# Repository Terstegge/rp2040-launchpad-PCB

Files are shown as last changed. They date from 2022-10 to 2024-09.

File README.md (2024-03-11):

# RP2040-Launchpad PCB

This repository contains the KiCad design files for a TI-style Launchpad board
with the RP2040 microcontroller. The board features a build-in picoprobe
debugger, which signals UART RX/TX and SWD activity with 3 LEDs. The unused
GPIO pins of the picoprobe are connected to a header, which could be used
in the future for more functionality like a simple logic analyzer etc.

The target RP2040 controller has 2 connected pushbuttons, one normal LED and
8 WS2812-2020 LEDs as input/output. Some signals are also available on a
horizonal header at the lower end of the PCB, which is used to connect WLAN or
Bluetooth boards like WifiTick. Both RP2040 (target and picoprobe) use a
4 MiB flash chip. The target RP2040 also has a button to enable programming
via the target USB port (mass storage device). Normally this button is
not needed, because all programming and debugging of the target is performed
via the picoprobe using openocd and gdb.

The board also contains a LiPo-charger to enable battery-powered projects.

Why was this board designed? I have been using the MSP432 Launchpad from TI for
quite a while in university classes teaching microcontroller technology.
Unfortunately TI has stopped producing all MSP432-related products. Still we
have purchased lots of TI boosterpack-boards like the Educational Boosterpack MK II.
The be able to used these Boosterpacks also in the future, a new Launchpad had
to be found. The RP2040 is a very interesting microcontroller, and, what is
quite important for educational purposes, it has excellent documentation.
So some days were spent and this board came to life.

The pictures below show version 1.3. The board features 2 user buttons and
a reset button on the lower edge. Additionally there is one
user-programmable simple red LED and a row of 8 WS2812 LEDS.
 
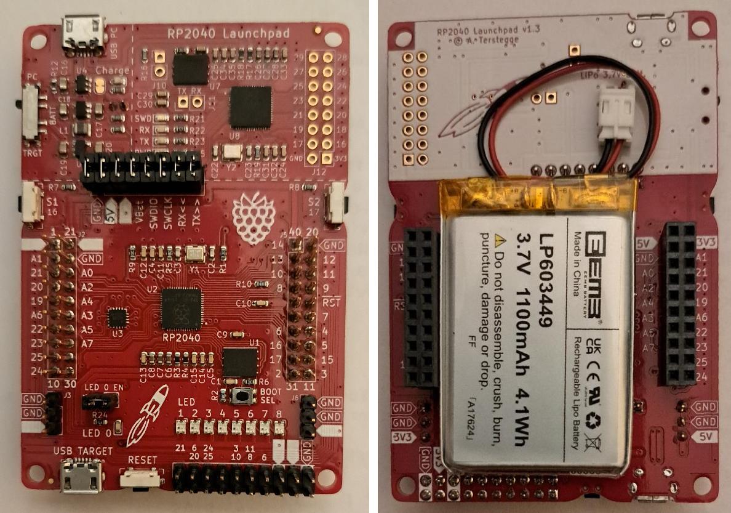
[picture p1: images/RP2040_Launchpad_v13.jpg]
RP2040 Lauchpad picture 1


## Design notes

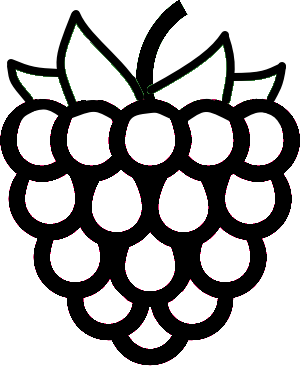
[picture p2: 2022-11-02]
images/raspberry.png

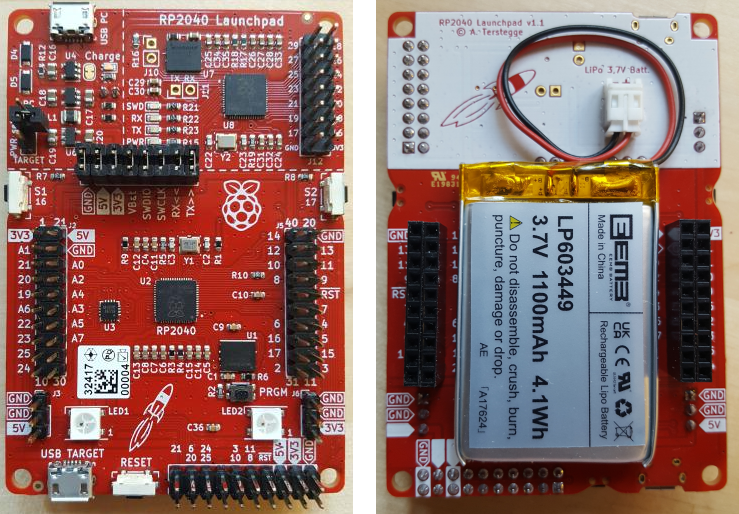
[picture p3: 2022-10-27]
images/rp2040-launchpad.png

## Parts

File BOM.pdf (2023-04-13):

rp2040-launchpad-PCB

Seite 1

ID | Bezeichner | Gehäuse | Stückzahl | Bezeichnung | Anbieter und Referenz
1 | J4 | PinHeader_2x10_P2.54mm_Vertical | 1 | LP Extension Heder
2 | G*** | Lauchpad-Logo | 1 | LOGO
3 | U9,U10,U11,U12,U13,U14,U15,U 16 | WS2812B-2020 | 8 | WS2812B-2020
4 | G***,G*** | raspberry | 2 | LOGO
5 | ,,, | | 4
6 | G***,G*** | Lauchpad-Energia-Logo | 2 | LOGO
7 | USB2 | USB-micro-B-Amph-10118194 | 1 | USB PC
8 | USB1 | USB-micro-B-Amph-10118194 | 1 | USB TARGET
9 | SW1 | DIPT-1188E | 1 | RESET
10 | S2 | DIPT-1188E | 1 | S2
11 | S1 | DIPT-1188E | 1 | S1
12 | SW2 | KMR2-Switch | 1 | BOOT
13 | J2 | PinHeader_2x10_P2.54mm_Vertical | 1 | LP Header left
14 | REF**,REF** | Fiducial_1mm_Mask2mm | 2 | Fiducial_1mm_Mask2mm
15 | U3 | QFN-16-1EP_3x3mm_P0.5mm_EP1.7x1.7mm | 1 | RS2299
16 | R11,R2,R5,R7,R8,R10,R15,R16, R19 | R_0603_1608Metric | 9 | 1k
17 | J8 | JST-S2B-PH-KL | 1 | LiPo 3,7V Batt.
18 | C1,C4,C5,C9,C10,C11,C12,C13, C14,C15,C21,C24,C25,C29,C30, C31,C32,C33,C34,C35 | C_0603_1608Metric | 20 | 100nF
19 | C2,C3,C22,C23 | C_0603_1608Metric | 4 | 22pF
20 | C6,C7,C8,C26,C27,C28 | C_0603_1608Metric | 6 | 1uF
21 | C16,C17,C18,C19,C20 | C_0805_2012Metric | 5 | 22u
22 | D3 | LED_0603_1608Metric | 1 | Charge
23 | D6 | LED_0603_1608Metric | 1 | PWR
24 | D7 | LED_0603_1608Metric | 1 | BLUE
25 | D8 | LED_0603_1608Metric | 1 | GREEN
26 | D9 | LED_0603_1608Metric | 1 | RED
27 | J1 | PinHeader_2x08_P2.54mm_Vertical | 1 | Target Isolation Jumpers
28 | J3,J6 | PinHeader_1x03_P2.54mm_Vertical | 2 | PWR Header
29 | J5 | PinHeader_2x10_P2.54mm_Vertical | 1 | LP Header right
30 | J7 | SolderJumper-2_P1.3mm_Bridged_RoundedPad1.0x1.5mm | 1 | Jumper
31 | J10 | PinHeader_1x02_P2.54mm_Vertical | 1 | DBG_PRGM
32 | J11 | PinHeader_1x02_P2.54mm_Vertical | 1 | UART_DBG
33 | J12 | PinHeader_2x08_P2.54mm_Vertical | 1 | DGB Exp. Header
34 | L1 | L_1008_2520Metric | 1 | 4u7
35 | R1,R6,R9,R20 | R_0603_1608Metric | 4 | 10k
36 | R3,R4,R17,R18 | R_0603_1608Metric | 4 | 27

rp2040-launchpad-PCB

Seite 2

37 | R12 | R_0603_1608Metric | 1 | 2k
38 | R13,R14 | R_0603_1608Metric | 2 | 100k
39 | R21,R22,R23,R24 | R_0603_1608Metric | 4 | 470
40 | U1,U7 | WSON-8-1EP_6x5mm_P1.27mm_EP3.4x4.3mm | 2 | 25Q32
41 | U2,U8 | QFN40P700X700X90-57N | 2 | RP2040
42 | U4 | SOT-23-5 | 1 | MCP73831
43 | U5 | SOT-23-5 | 1 | XC9142B50C
44 | U6 | SOT-23-5 | 1 | XC6220B33
45 | Y1,Y2 | Crystal_SMD_TXC_7M-4Pin_3.2x2.5mm | 2 | 12MHz
46 | D1 | LED_0603_1608Metric | 1 | LED 0
47 | J13 | PinHeader_1x02_P2.54mm_Vertical | 1 | LED 0 EN
48 | SW3 | PCM13SMTR | 1 | Switch_SP3T

kein Bauteil
THT Bauteil, vor vom Kunden betstückt
SMD Bauteil, wird vom Kunden beigestellt
SMD R/C, wird von Fa Kuttig gestellt

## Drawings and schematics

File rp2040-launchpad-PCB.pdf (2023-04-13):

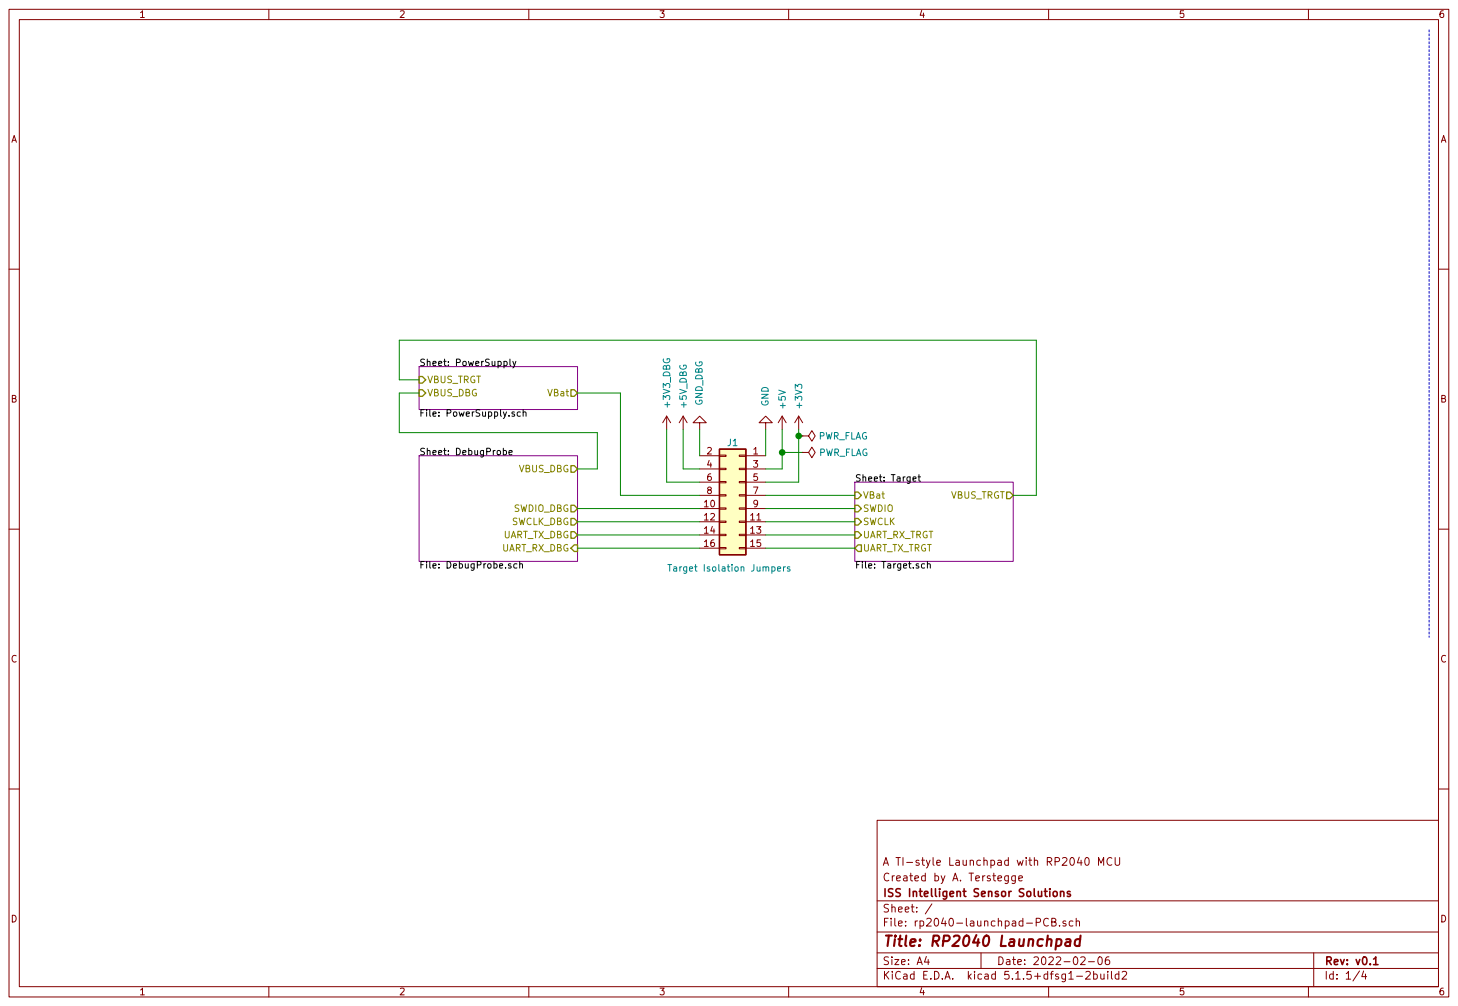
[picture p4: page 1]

SWDIO
File: Target.sch SWCLK

12 | 11
14 | 13
16 | 15

A TI-style Launchpad with RP2040 MCU
Created by A. Terstegge
ISS Intelligent Sensor Solutions
File: rp2040-launchpad-PCB.sch Sheet: /
Id: 1/4 Title: RP2040 Launchpad

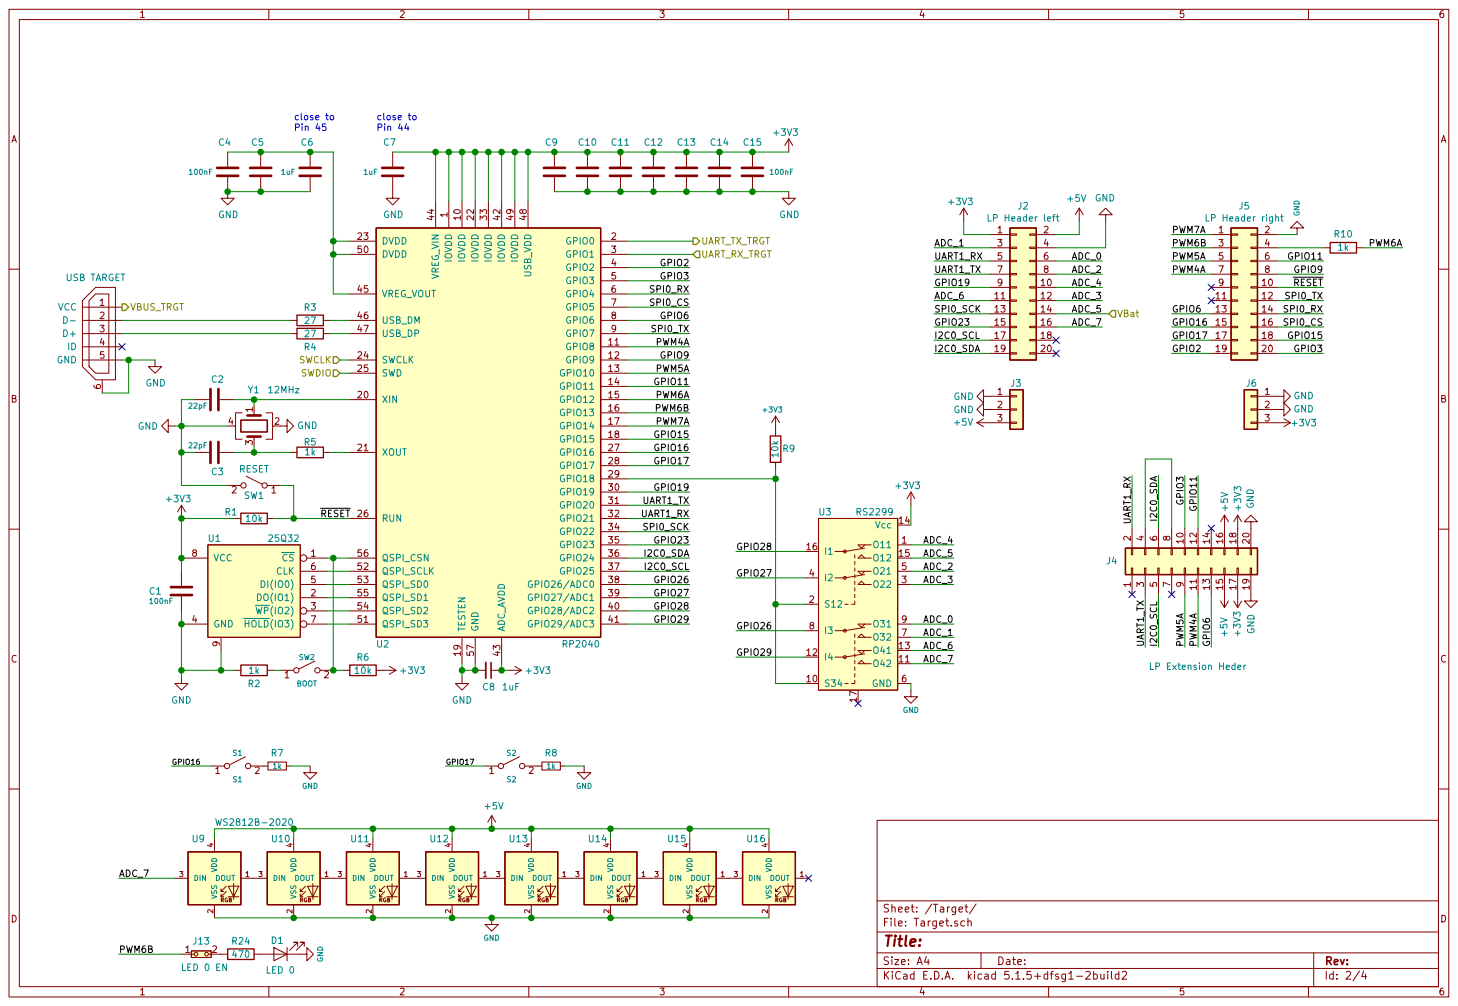
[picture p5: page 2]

1 IOVDD 10 GPIO8 11 GPIO9 12 GPIO10 13 GPIO11 14 GPIO12 15 GPIO13 16 GPIO14 17 GPIO15 18 TESTEN 19 GPIO0 2 XIN 20 XOUT 21 IOVDD 22 DVDD 23 SWCLK 24 SWD 25 RUN 26 GPIO16 27 GPIO17 28 GPIO18 29 GPIO1 3 GPIO19 30 GPIO20 31 GPIO21 32 IOVDD 33 GPIO22 34 GPIO23 35 GPIO24 36 GPIO25 37 GPIO26/ADC0 38 GPIO27/ADC1 39 GPIO2 4 GPIO28/ADC2 40 GPIO29/ADC3 41 IOVDD 42 ADC_AVDD 43 VREG_VIN 44 VREG_VOUT 45 USB_DM 46 USB_DP 47 USB_VDD 48 IOVDD 49 GPIO3 5 DVDD 50 QSPI_SD3 51 QSPI_SCLK 52 QSPI_SD0 53 QSPI_SD2 54 QSPI_SD1 55 QSPI_CSN 56 GND 57 GPIO4 6 GPIO5 7 GPIO6 8 GPIO7 9 U2 RP2040

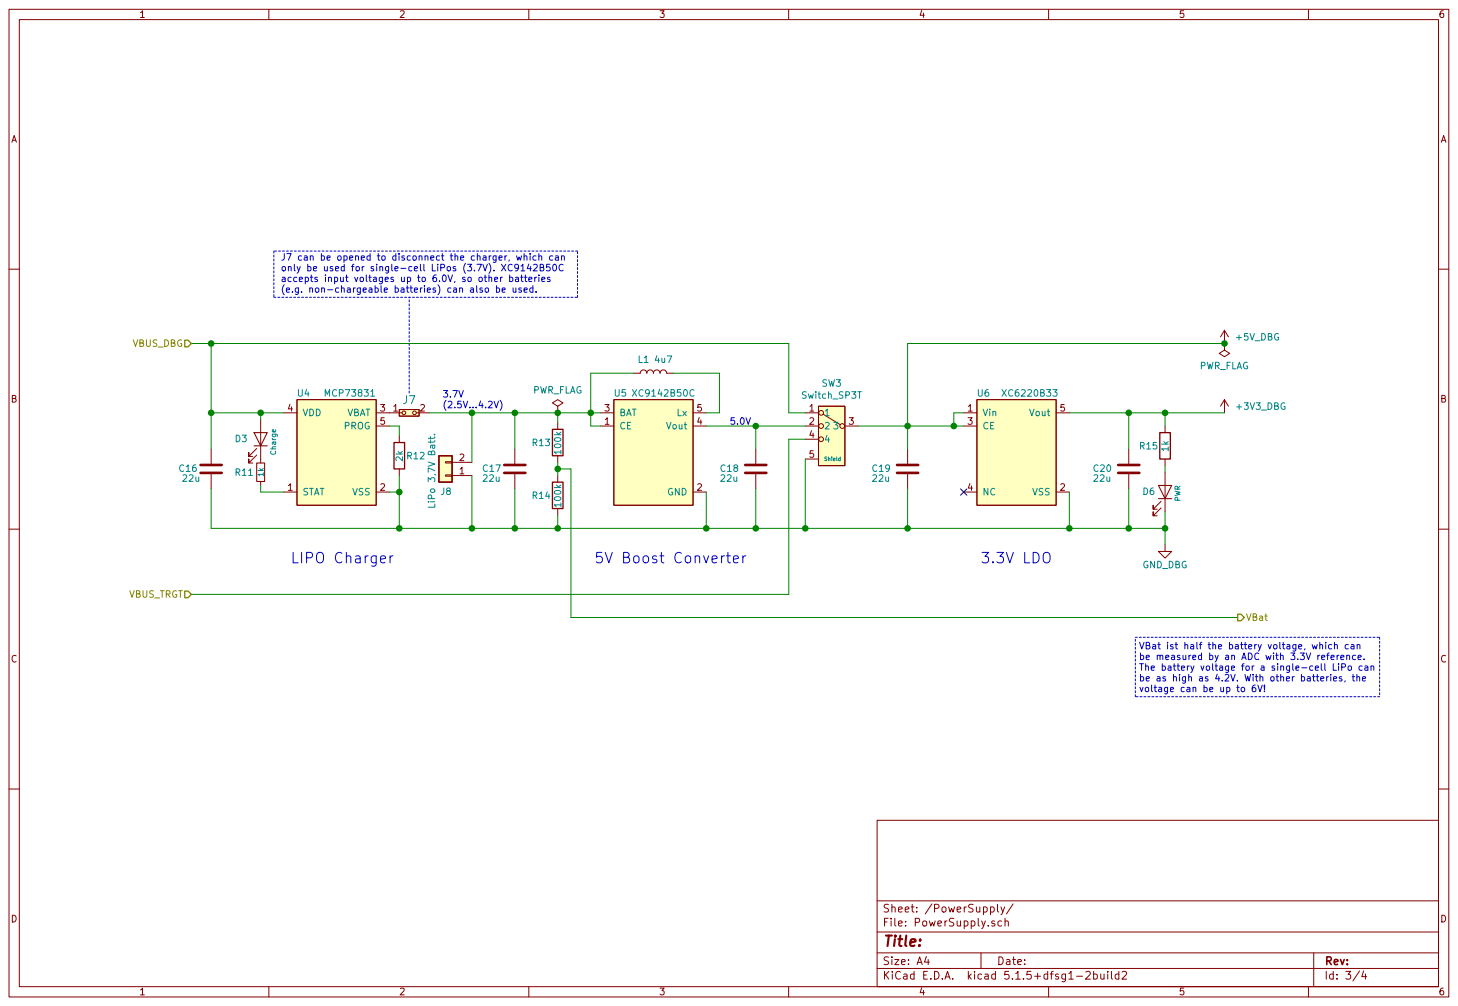
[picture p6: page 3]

J7 can be opened to disconnect the charger, which can
only be used for single-cell LiPos (3.7V). XC9142B50C
accepts input voltages up to 6.0V, so other batteries
(e.g. non-chargeable batteries) can also be used. 3.7V

be measured by an ADC with 3.3V reference.
The battery voltage for a single-cell LiPo can
be as high as 4.2V. With other batteries, the
voltage can be up to 6V!

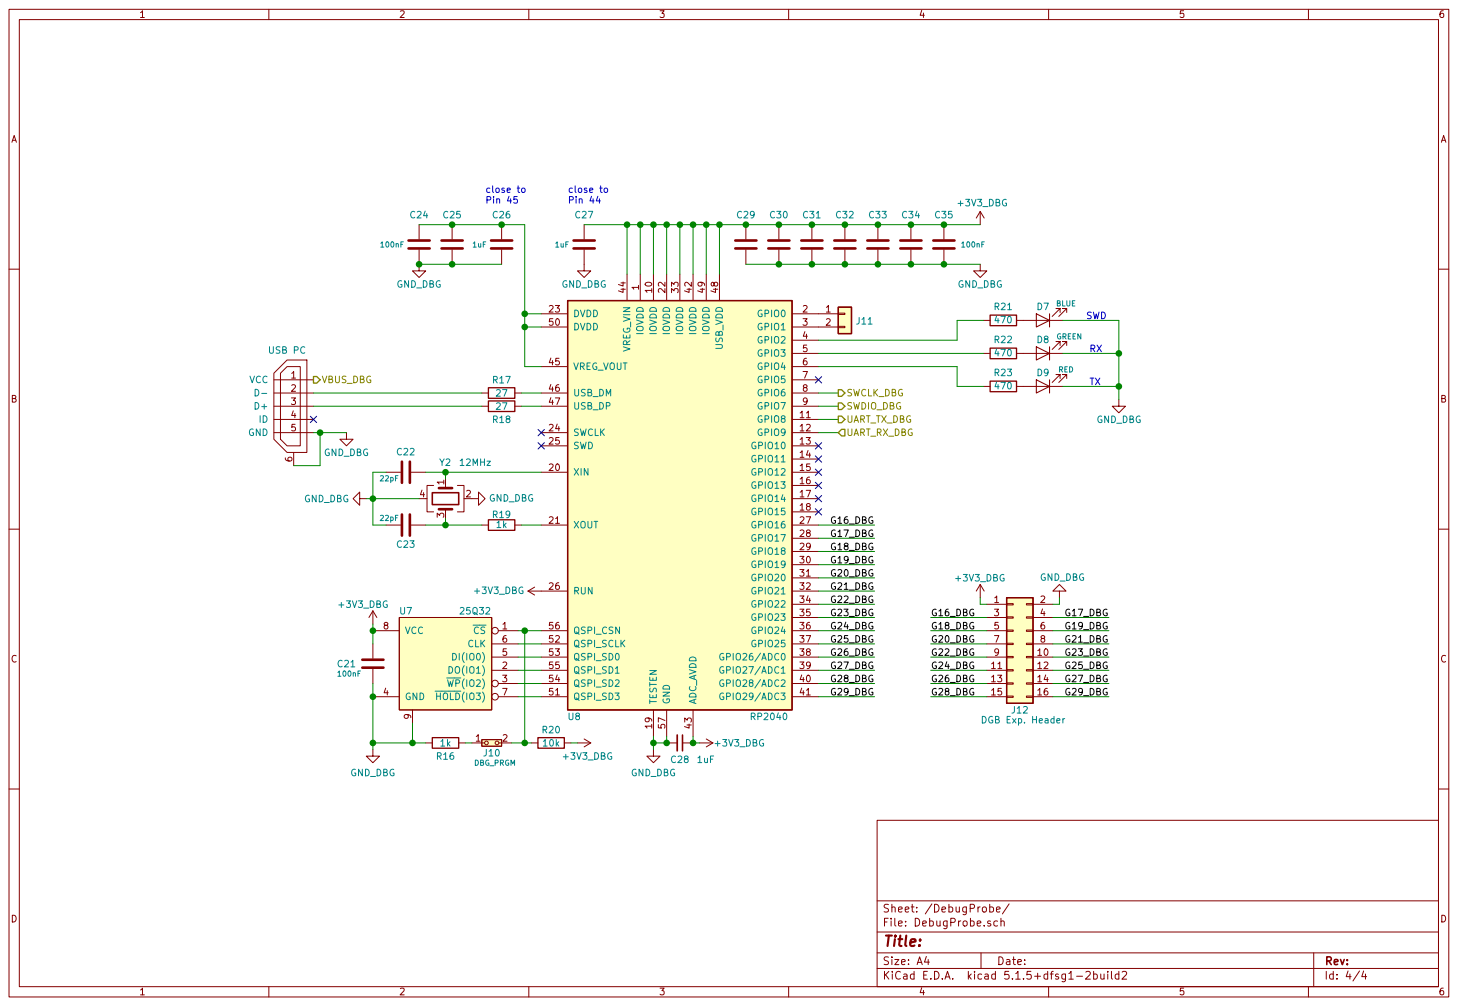
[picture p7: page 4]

1 IOVDD 10 GPIO8 11 GPIO9 12 GPIO10 13 GPIO11 14 GPIO12 15 GPIO13 16 GPIO14 17 GPIO15 18 TESTEN 19 GPIO0 2 XIN 20 XOUT 21 IOVDD 22 DVDD 23 SWCLK 24 SWD 25 RUN 26 GPIO16 27 GPIO17 28 GPIO18 29 GPIO1 3 GPIO19 30 GPIO20 31 GPIO21 32 IOVDD 33 GPIO22 34 GPIO23 35 GPIO24 36 GPIO25 37 GPIO26/ADC0 38 GPIO27/ADC1 39 GPIO2 4 GPIO28/ADC2 40 GPIO29/ADC3 41 IOVDD 42 ADC_AVDD 43 VREG_VIN 44 VREG_VOUT 45 USB_DM 46 USB_DP 47 USB_VDD 48 IOVDD 49 GPIO3 5 DVDD 50 QSPI_SD3 51 QSPI_SCLK 52 QSPI_SD0 53 QSPI_SD2 54 QSPI_SD1 55 QSPI_CSN 56 GND 57 GPIO4 6 GPIO5 7 GPIO6 8 GPIO7 9 U8 RP2040

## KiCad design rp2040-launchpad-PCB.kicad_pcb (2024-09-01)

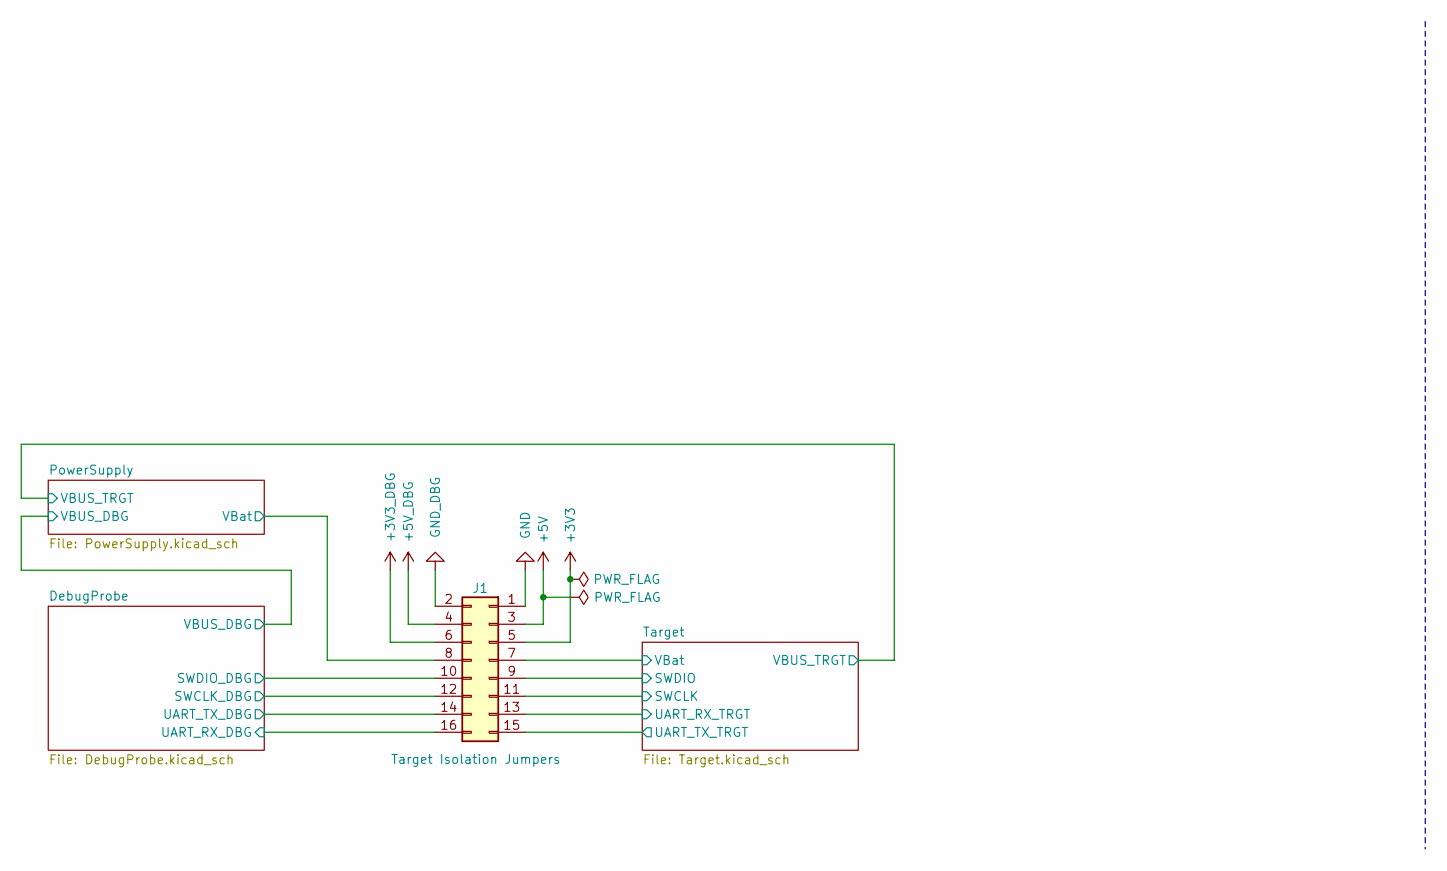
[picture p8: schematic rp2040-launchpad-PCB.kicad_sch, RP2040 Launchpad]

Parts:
J1: Target Isolation Jumpers; PinHeader_2x08_P2.54mm_Vertical

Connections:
+3V3: J1.5; also elsewhere on the board
+3V3_DBG: J1.6; also elsewhere on the board
+5V: J1.3; also elsewhere on the board
+5V_DBG: J1.4; also elsewhere on the board
/DebugProbe/SWCLK_DBG: J1.12; also elsewhere on the board
/DebugProbe/SWDIO_DBG: J1.10; also elsewhere on the board
/DebugProbe/UART_RX_DBG: J1.16; also elsewhere on the board
/DebugProbe/UART_TX_DBG: J1.14; also elsewhere on the board
/PowerSupply/VBat: J1.8; also elsewhere on the board
/Target/SWCLK: J1.11; also elsewhere on the board
/Target/SWDIO: J1.9; also elsewhere on the board
/Target/UART_RX_TRGT: J1.13; also elsewhere on the board
/Target/UART_TX_TRGT: J1.15; also elsewhere on the board
/Target/VBat: J1.7; also elsewhere on the board
GND: J1.1; also elsewhere on the board
GND_DBG: J1.2; also elsewhere on the board

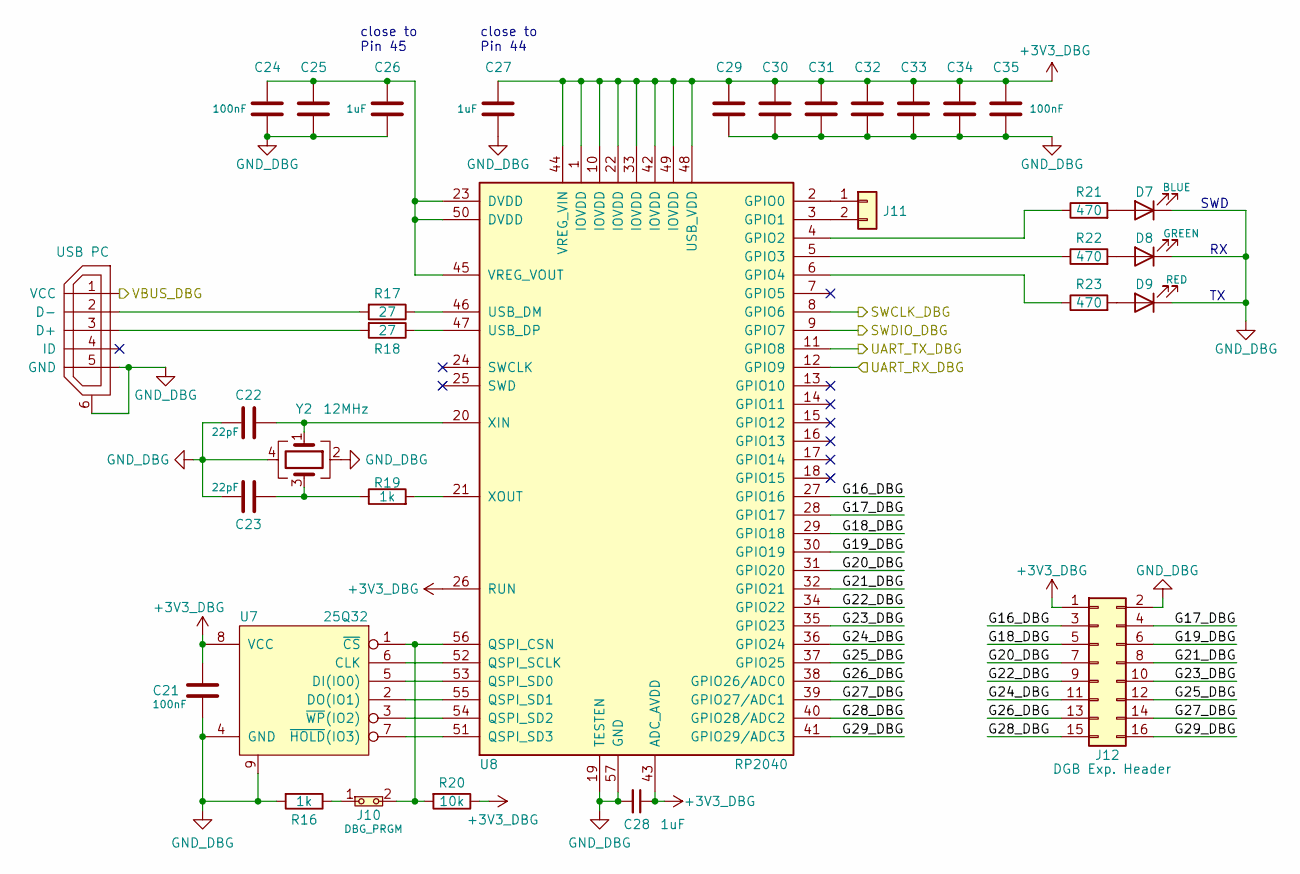
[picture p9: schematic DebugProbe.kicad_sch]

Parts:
C21, C24, C25, C29, C30, C31, C32, C33, C34, C35: 100nF; C_0603_1608Metric
C22, C23: 22pF; C_0603_1608Metric
C26, C27, C28: 1uF; C_0603_1608Metric
D7: BLUE; LED_0603_1608Metric
D8: GREEN; LED_0603_1608Metric
D9: RED; LED_0603_1608Metric
J10: DBG_PRGM; PinHeader_1x02_P2.54mm_Vertical
J11: UART_DBG; PinHeader_1x02_P2.54mm_Vertical
J12: DGB Exp. Header; PinHeader_2x08_P2.54mm_Vertical
R16, R19: 1k; R_0603_1608Metric
R17, R18: 27; R_0603_1608Metric
R20: 10k; R_0603_1608Metric
R21, R22, R23: 470; R_0603_1608Metric
U7: 25Q32; WSON-8-1EP_6x5mm_P1.27mm_EP3.4x4.3mm
U8: RP2040; QFN40P700X700X90-57N; PARTREV 1.6.1
USB2: USB PC; USB-micro-B-Amph-10118194
Y2: 12MHz; Crystal_SMD_TXC_7M-4Pin_3.2x2.5mm

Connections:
+3V3_DBG: C21.1, C27.1, C28.1, C29.1, C30.1, C31.1, C32.1, C33.1, C34.1, C35.1, J12.1, R20.1, U7.8 (VCC), U8.1 (IOVDD), U8.10 (IOVDD), U8.22 (IOVDD), U8.26 (RUN), U8.33 (IOVDD), U8.42 (IOVDD), U8.43 (ADC_AVDD), U8.44 (VREG_VIN), U8.48 (USB_VDD), U8.49 (IOVDD); also elsewhere on the board
/DebugProbe/G16_DBG: J12.3, U8.27 (GPIO16)
/DebugProbe/G17_DBG: J12.4, U8.28 (GPIO17)
/DebugProbe/G18_DBG: J12.5, U8.29 (GPIO18)
/DebugProbe/G19_DBG: J12.6, U8.30 (GPIO19)
/DebugProbe/G20_DBG: J12.7, U8.31 (GPIO20)
/DebugProbe/G21_DBG: J12.8, U8.32 (GPIO21)
/DebugProbe/G22_DBG: J12.9, U8.34 (GPIO22)
/DebugProbe/G23_DBG: J12.10, U8.35 (GPIO23)
/DebugProbe/G24_DBG: J12.11, U8.36 (GPIO24)
/DebugProbe/G25_DBG: J12.12, U8.37 (GPIO25)
/DebugProbe/G26_DBG: J12.13, U8.38 (GPIO26/ADC0)
/DebugProbe/G27_DBG: J12.14, U8.39 (GPIO27/ADC1)
/DebugProbe/G28_DBG: J12.15, U8.40 (GPIO28/ADC2)
/DebugProbe/G29_DBG: J12.16, U8.41 (GPIO29/ADC3)
/DebugProbe/SWCLK_DBG: U8.8 (GPIO6); also elsewhere on the board
/DebugProbe/SWDIO_DBG: U8.9 (GPIO7); also elsewhere on the board
/DebugProbe/UART_RX_DBG: U8.12 (GPIO9); also elsewhere on the board
/DebugProbe/UART_TX_DBG: U8.11 (GPIO8); also elsewhere on the board
/DebugProbe/VBUS_DBG: USB2.1 (VCC); also elsewhere on the board
GND_DBG: C21.2, C22.1, C23.1, C24.2, C25.2, C26.2, C27.2, C28.2, C29.2, C30.2, C31.2, C32.2, C33.2, C34.2, C35.2, D7.1 (K), D8.1 (K), D9.1 (K), J12.2, R16.2, U7.4 (GND), U7.9, U8.19 (TESTEN), U8.57 (GND), USB2.5 (GND), USB2.6, Y2.2, Y2.4; also elsewhere on the board
unnamed: C22.2, U8.20 (XIN), Y2.1
unnamed: C23.2, R19.1, Y2.3
unnamed: C24.1, C25.1, C26.1, U8.23 (DVDD), U8.45 (VREG_VOUT), U8.50 (DVDD)
unnamed: D7.2 (A), R21.2
unnamed: D8.2 (A), R22.2
unnamed: D9.2 (A), R23.2
unnamed: J10.1, R16.1
unnamed: J10.2, R20.2, U7.1 (~CS), U8.56 (QSPI_CSN)
unnamed: J11.1, U8.2 (GPIO0)
unnamed: J11.2, U8.3 (GPIO1)
unnamed: R17.1, U8.46 (USB_DM)
unnamed: R17.2, USB2.2 (D-)
unnamed: R18.1, U8.47 (USB_DP)
unnamed: R18.2, USB2.3 (D+)
unnamed: R19.2, U8.21 (XOUT)
unnamed: R21.1, U8.4 (GPIO2)
unnamed: R22.1, U8.5 (GPIO3)
unnamed: R23.1, U8.6 (GPIO4)
unnamed: U7.2 (DO(IO1)), U8.55 (QSPI_SD1)
unnamed: U7.3 (~WP(IO2)), U8.54 (QSPI_SD2)
unnamed: U7.5 (DI(IO0)), U8.53 (QSPI_SD0)
unnamed: U7.6 (CLK), U8.52 (QSPI_SCLK)
unnamed: U7.7 (~HOLD(IO3)), U8.51 (QSPI_SD3)

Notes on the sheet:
SWD
close to Pin 45
close to Pin 44

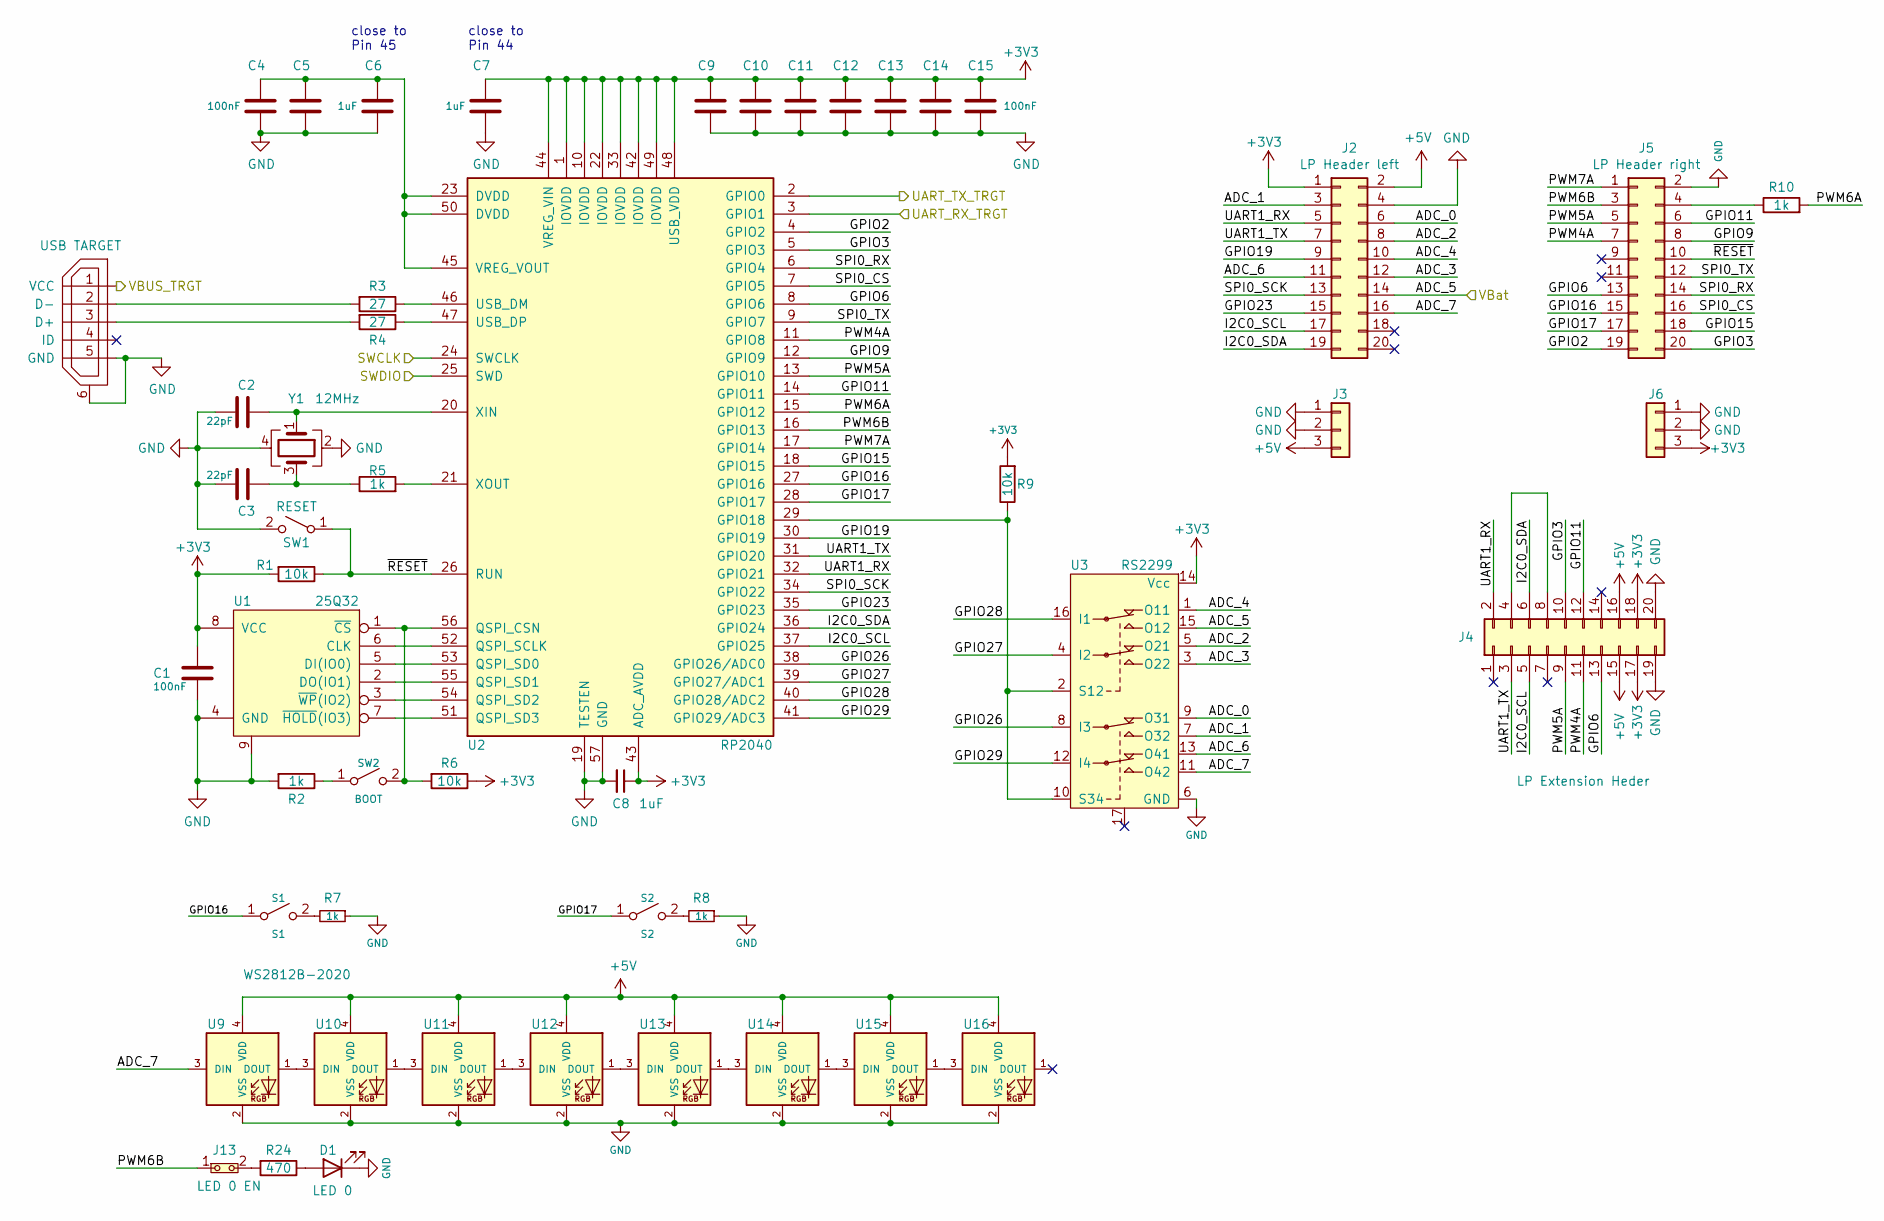
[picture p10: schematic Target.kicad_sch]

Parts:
C1, C4, C5, C9, C10, C11, C12, C13, C14, C15: 100nF; C_0603_1608Metric
C2, C3: 22pF; C_0603_1608Metric
C6, C7, C8: 1uF; C_0603_1608Metric
D1: LED 0; LED_0603_1608Metric
J2: LP Header left; PinHeader_2x10_P2.54mm_Vertical
J3, J6: PWR Header; PinHeader_1x03_P2.54mm_Vertical
J4: LP Extension Heder; PinHeader_2x10_P2.54mm_Vertical
J5: LP Header right; PinHeader_2x10_P2.54mm_Vertical
J13: LED 0 EN; PinHeader_1x02_P2.54mm_Vertical
R1, R6, R9: 10k; R_0603_1608Metric
R2, R5, R7, R8, R10: 1k; R_0603_1608Metric
R3, R4: 27; R_0603_1608Metric
R24: 470; R_0603_1608Metric
S1: S1; DIPT-1188E
S2: S2; DIPT-1188E
SW1: RESET; DIPT-1188E
SW2: BOOT; KMR2-Switch
U1: 25Q32; WSON-8-1EP_6x5mm_P1.27mm_EP3.4x4.3mm
U2: RP2040; QFN40P700X700X90-57N; PARTREV 1.6.1
U3: RS2299; QFN-16-1EP_3x3mm_P0.5mm_EP1.7x1.7mm
U9, U10, U11, U12, U13, U14, U15, U16: WS2812B-2020
USB1: USB TARGET; USB-micro-B-Amph-10118194
Y1: 12MHz; Crystal_SMD_TXC_7M-4Pin_3.2x2.5mm

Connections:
+3V3: C1.1, C7.1, C8.1, C9.1, C10.1, C11.1, C12.1, C13.1, C14.1, C15.1, J2.1, J4.17, J4.18, J6.3, R1.2, R6.1, R9.2, U1.8 (VCC), U2.1 (IOVDD), U2.10 (IOVDD), U2.22 (IOVDD), U2.33 (IOVDD), U2.42 (IOVDD), U2.43 (ADC_AVDD), U2.44 (VREG_VIN), U2.48 (USB_VDD), U2.49 (IOVDD), U3.14 (Vcc); also elsewhere on the board
+5V: J2.2, J3.3, J4.15, J4.16, U9.4 (VDD), U10.4 (VDD), U11.4 (VDD), U12.4 (VDD), U13.4 (VDD), U14.4 (VDD), U15.4 (VDD), U16.4 (VDD); also elsewhere on the board
/PowerSupply/VBUS_TRGT: USB1.1 (VCC); also elsewhere on the board
/Target/ADC_0: J2.6, U3.9 (O31)
/Target/ADC_1: J2.3, U3.7 (O32)
/Target/ADC_2: J2.8, U3.5 (O21)
/Target/ADC_3: J2.12, U3.3 (O22)
/Target/ADC_4: J2.10, U3.1 (O11)
/Target/ADC_6: J2.11, U3.13 (O41)
/Target/ADC_7: J2.16, U3.11 (O42), U9.3 (DIN)
/Target/GPIO2: J5.19, U2.4 (GPIO2)
/Target/GPIO3: J4.10, J5.20, U2.5 (GPIO3)
/Target/GPIO6: J4.13, J5.13, U2.8 (GPIO6)
/Target/GPIO9: J5.8, U2.12 (GPIO9)
/Target/GPIO11: J4.12, J5.6, U2.14 (GPIO11)
/Target/GPIO15: J5.18, U2.18 (GPIO15)
/Target/GPIO16: J5.15, S1.1 (A), U2.27 (GPIO16)
/Target/GPIO17: J5.17, S2.1 (A), U2.28 (GPIO17)
/Target/GPIO19: J2.9, U2.30 (GPIO19)
/Target/GPIO23: J2.15, U2.35 (GPIO23)
/Target/GPIO26: U2.38 (GPIO26/ADC0), U3.8 (I3)
/Target/GPIO27: U2.39 (GPIO27/ADC1), U3.4 (I2)
/Target/GPIO28: U2.40 (GPIO28/ADC2), U3.16 (I1)
/Target/GPIO29: U2.41 (GPIO29/ADC3), U3.12 (I4)
/Target/I2C0_SCL: J2.17, J4.5, U2.37 (GPIO25)
/Target/I2C0_SDA: J2.19, J4.6, U2.36 (GPIO24)
/Target/PWM4A: J4.11, J5.7, U2.11 (GPIO8)
/Target/PWM5A: J4.9, J5.5, U2.13 (GPIO10)
/Target/PWM6A: R10.2, U2.15 (GPIO12)
/Target/PWM6B: J5.3, J13.1, U2.16 (GPIO13)
/Target/PWM7A: J5.1, U2.17 (GPIO14)
/Target/SPI0_CS: J5.16, U2.7 (GPIO5)
/Target/SPI0_RX: J5.14, U2.6 (GPIO4)
/Target/SPI0_SCK: J2.13, U2.34 (GPIO22)
/Target/SPI0_TX: J5.12, U2.9 (GPIO7)
/Target/SWCLK: U2.24 (SWCLK); also elsewhere on the board
/Target/SWDIO: U2.25 (SWD); also elsewhere on the board
/Target/UART1_RX: J2.5, J4.2, U2.32 (GPIO21)
/Target/UART1_TX: J2.7, J4.3, U2.31 (GPIO20)
/Target/UART_RX_TRGT: U2.3 (GPIO1); also elsewhere on the board
/Target/UART_TX_TRGT: U2.2 (GPIO0); also elsewhere on the board
/Target/VBat: J2.14, U3.15 (O12); also elsewhere on the board
/Target/~RESET: J5.10, R1.1, SW1.1 (A), U2.26 (RUN)
GND: C1.2, C2.1, C3.1, C4.2, C5.2, C6.2, C7.2, C8.2, C9.2, C10.2, C11.2, C12.2, C13.2, C14.2, C15.2, D1.1 (K), J2.4, J3.1, J3.2, J4.19, J4.20, J5.2, J6.1, J6.2, R2.2, R7.1, R8.1, SW1.2 (B), U1.4 (GND), U1.9, U2.19 (TESTEN), U2.57 (GND), U3.6 (GND), U9.2 (VSS), U10.2 (VSS), U11.2 (VSS), U12.2 (VSS), U13.2 (VSS), U14.2 (VSS), U15.2 (VSS), U16.2 (VSS), USB1.5 (GND), USB1.6, Y1.2, Y1.4; also elsewhere on the board
unnamed: C2.2, U2.20 (XIN), Y1.1
unnamed: C3.2, R5.1, Y1.3
unnamed: C4.1, C5.1, C6.1, U2.23 (DVDD), U2.45 (VREG_VOUT), U2.50 (DVDD)
unnamed: D1.2 (A), R24.1
unnamed: J4.4, J4.8
unnamed: J5.4, R10.1
unnamed: J13.2, R24.2
unnamed: R2.1, SW2.1 (A)
unnamed: R3.1, U2.46 (USB_DM)
unnamed: R3.2, USB1.2 (D-)
unnamed: R4.1, U2.47 (USB_DP)
unnamed: R4.2, USB1.3 (D+)
unnamed: R5.2, U2.21 (XOUT)
unnamed: R6.2, SW2.2 (B), U1.1 (~CS), U2.56 (QSPI_CSN)
unnamed: R7.2, S1.2 (B)
unnamed: R8.2, S2.2 (B)
unnamed: R9.1, U2.29 (GPIO18), U3.2 (S12), U3.10 (S34)
unnamed: U1.2 (DO(IO1)), U2.55 (QSPI_SD1)
unnamed: U1.3 (~WP(IO2)), U2.54 (QSPI_SD2)
unnamed: U1.5 (DI(IO0)), U2.53 (QSPI_SD0)
unnamed: U1.6 (CLK), U2.52 (QSPI_SCLK)
unnamed: U1.7 (~HOLD(IO3)), U2.51 (QSPI_SD3)
unnamed: U10.1 (DOUT), U11.3 (DIN)
unnamed: U9.1 (DOUT), U10.3 (DIN)
unnamed: U11.1 (DOUT), U12.3 (DIN)
unnamed: U12.1 (DOUT), U13.3 (DIN)
unnamed: U13.1 (DOUT), U14.3 (DIN)
unnamed: U14.1 (DOUT), U15.3 (DIN)
unnamed: U15.1 (DOUT), U16.3 (DIN)

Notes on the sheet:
close to Pin 44
close to Pin 45

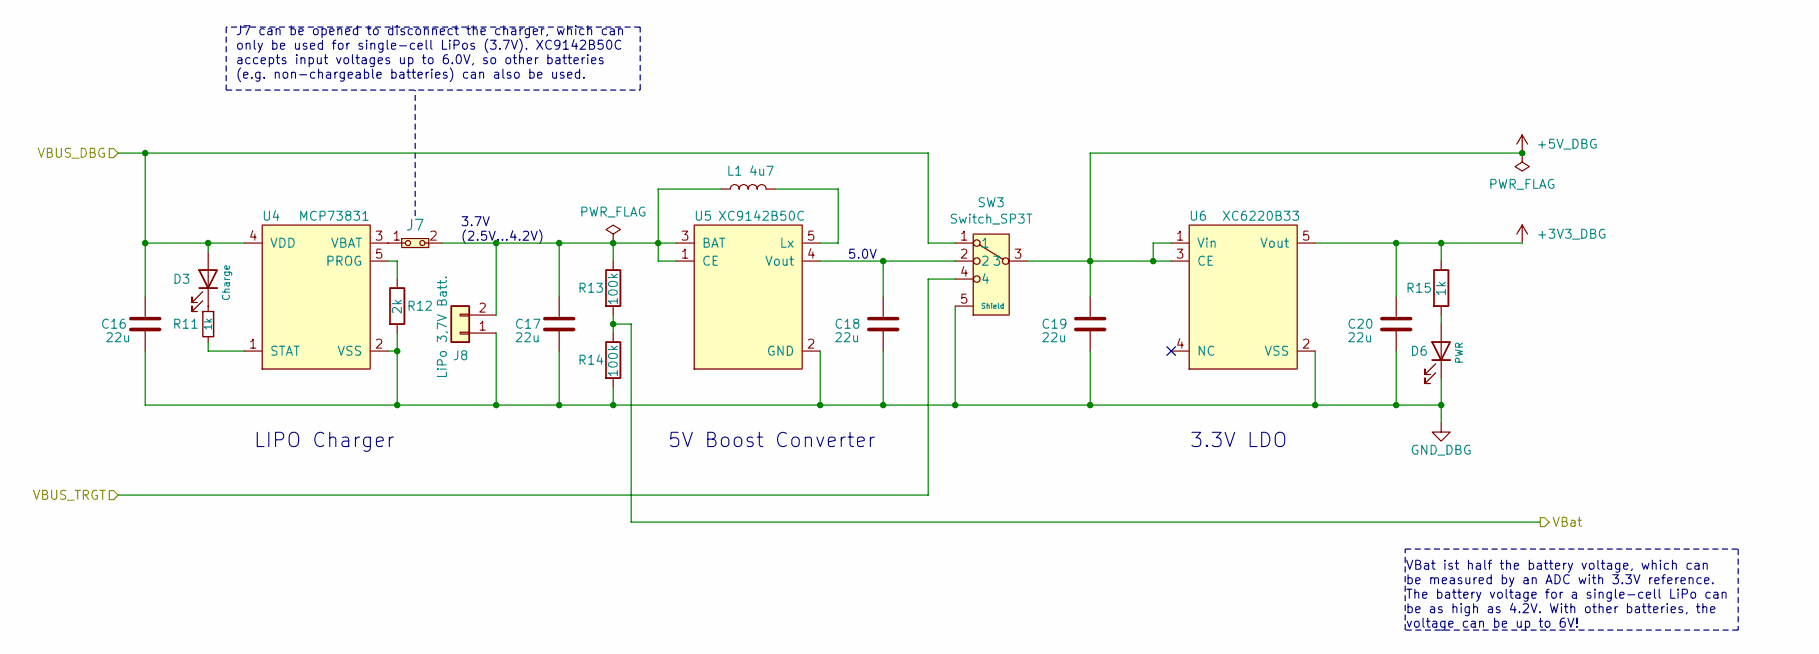
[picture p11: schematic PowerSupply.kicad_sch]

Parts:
C16, C17, C18, C19, C20: 22u; C_0805_2012Metric
D3: Charge; LED_0603_1608Metric
D6: PWR; LED_0603_1608Metric
J7: Jumper; SolderJumper-2_P1.3mm_Bridged_RoundedPad1.0x1.5mm
J8: LiPo 3,7V Batt.; JST-S2B-PH-KL
L1: 4u7; L_1008_2520Metric
R11, R15: 1k; R_0603_1608Metric
R12: 2k; R_0603_1608Metric
R13, R14: 100k; R_0603_1608Metric
SW3: Switch_SP3T; PCM13SMTR
U4: MCP73831; SOT-23-5
U5: XC9142B50C; SOT-23-5
U6: XC6220B33; SOT-23-5

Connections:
+3V3_DBG: C20.2, R15.1, U6.5 (Vout); also elsewhere on the board
+5V_DBG: C19.2, SW3.3, U6.1 (Vin), U6.3 (CE); also elsewhere on the board
/DebugProbe/VBUS_DBG: C16.2, D3.2 (A), SW3.1, U4.4 (VDD); also elsewhere on the board
/PowerSupply/VBUS_TRGT: SW3.4; also elsewhere on the board
/PowerSupply/VBat: R13.2, R14.1; also elsewhere on the board
GND_DBG: C16.1, C17.1, C18.1, C19.1, C20.1, D6.1 (K), J8.1, R12.2, R14.2, SW3.5 (Shield), U4.2 (VSS), U5.2 (GND), U6.2 (VSS); also elsewhere on the board
unnamed: C17.2, J7.2, J8.2, L1.1, R13.1, U5.1 (CE), U5.3 (BAT)
unnamed: C18.2, SW3.2, U5.4 (Vout)
unnamed: D3.1 (K), R11.1
unnamed: D6.2 (A), R15.2
unnamed: J7.1, U4.3 (VBAT)
unnamed: L1.2, U5.5 (Lx)
unnamed: R11.2, U4.1 (STAT)
unnamed: R12.1, U4.5 (PROG)

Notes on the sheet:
3.7V (2.5V...4.2V)
3.3V LDO
5V Boost Converter
VBat ist half the battery voltage, which can be measured by an ADC with 3.3V reference. The battery voltage for a single-cell LiPo can be as high as 4.2V. With other batteries, the voltage can be up to 6V!
LIPO Charger
J7 can be opened to disconnect the charger, which can only be used for single-cell LiPos (3.7V). XC9142B50C accepts input voltages up to 6.0V, so other batteries (e.g. non-chargeable batteries) can also be used.
5.0V

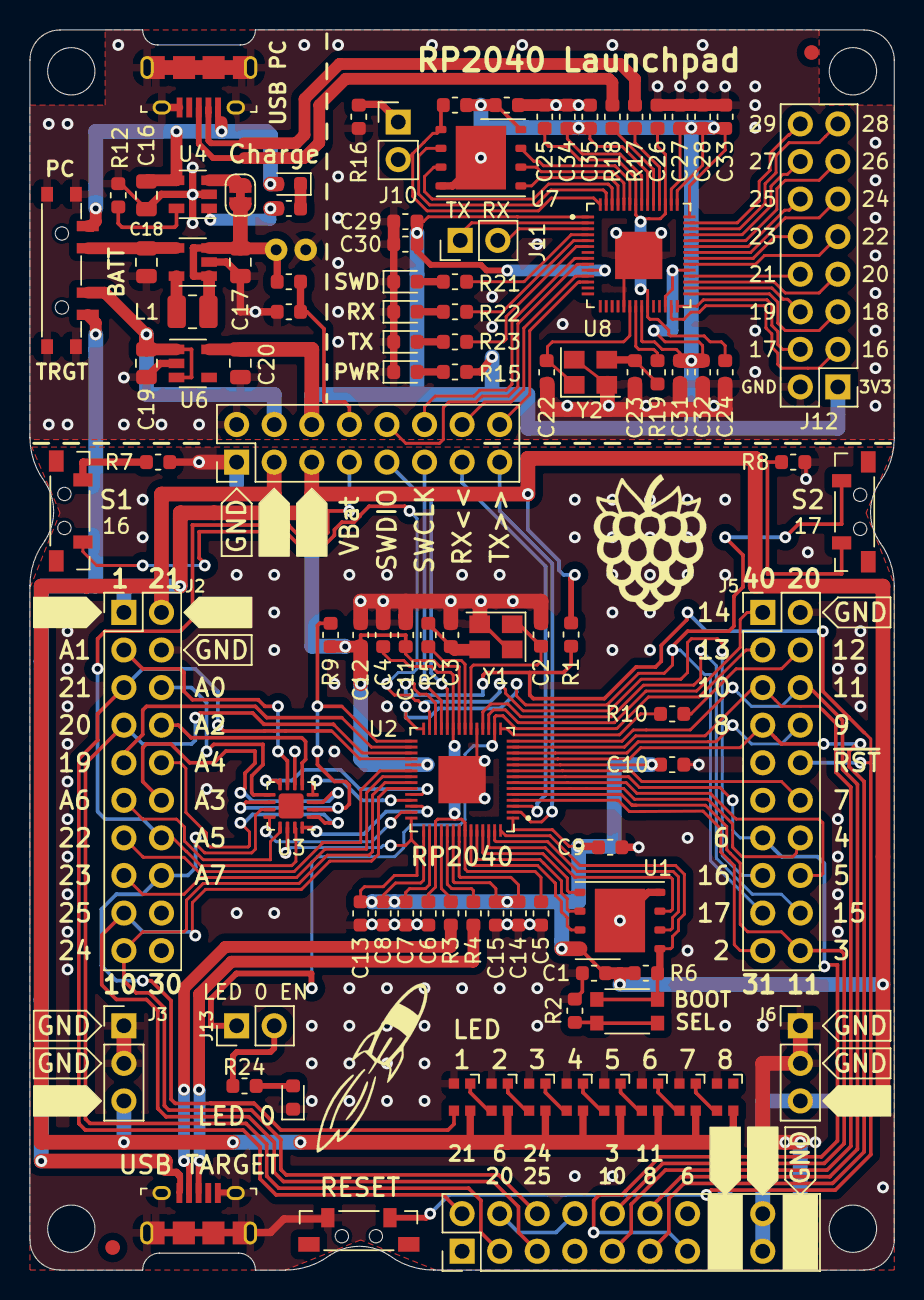
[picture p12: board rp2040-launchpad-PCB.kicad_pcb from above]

Board: 2 copper layers, 58.4 x 83.8 mm, 103 parts (1 on the bottom side), 127 nets.

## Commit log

2022-10-27 First commit with local version.
    [DebugProbe.sch, PowerSupply.sch, Target.sch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]
2022-10-27 Added schematic file. Added gerber files. Updated README.
    [rp2040-launchpad-PCB-B_Cu.gbr, rp2040-launchpad-PCB-B_Mask.gbr, rp2040-launchpad-PCB-B_Paste.gbr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]
2022-11-02 Changed Raspberry logo. Added more vias around LiPo charger.
    [BOM.csv, BOM.ods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]
2022-11-02 Small fix in layout below rp2040 (probe).
    [rp2040-launchpad-PCB-B_Cu.gbr, rp2040-launchpad-PCB-B_Mask.gbr, rp2040-launchpad-PCB-B_Paste.gbr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]
2022-11-02 Updated BOM and logo (png)
    [BOM.ods]
2022-11-22 Added Pin1 silk for WS2812-2020 footprint. Generated new pos-Files because U9-U16 were missing.
    [BOM.csv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]
2023-01-27 New version 1.3 - first commit
    [BOM.csv, DebugProbe.sch, PowerSupply.sch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]
2023-01-27 Deleted double footprint folder - regenerated all production files just to be sure...
    [rp2040-launchpad-PCB-B_Cu.gbr, rp2040-launchpad-PCB-B_Mask.gbr, rp2040-launchpad-PCB-B_Paste.gbr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]
2023-01-27 BOM updated
    [BOM.csv]
2023-03-08 Version v1.3 finalized. Ready for production!
    [BOM.csv, Target.sch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]
2023-04-13 Smaller changes and BOM update.
    [BOM.ods, rp2040-launchpad-PCB.ods]
2024-09-01 Migration to KiCad version 8
    [DebugProbe.kicad_sch, DebugProbe.sch, PowerSupply.kicad_sch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]

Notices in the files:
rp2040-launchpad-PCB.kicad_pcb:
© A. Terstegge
